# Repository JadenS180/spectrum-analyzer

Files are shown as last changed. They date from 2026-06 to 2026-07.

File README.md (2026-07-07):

# ESP32 Audio Spectrum Analyzer

A real-time audio spectrum analyzer built on the ESP32, featuring a custom-designed PCB. Captures audio via an I2S MEMS microphone, runs FFT processing on-chip, displays a live 16-bar frequency spectrum on an OLED display, and streams real-time FFT data over WiFi to a browser-based visualizer via WebSockets.

---

## Demo Videos

**Analyzer reacting to noise:**

https://github.com/JadenS180/spectrum-analyzer/raw/main/media/spectrum-DemoNoise.MOV

**Analyzer in a quiet environment:**

https://github.com/JadenS180/spectrum-analyzer/raw/main/media/spectrum-DemoQuiet.MOV

---

## Web Dashboard

### Reacting to noise
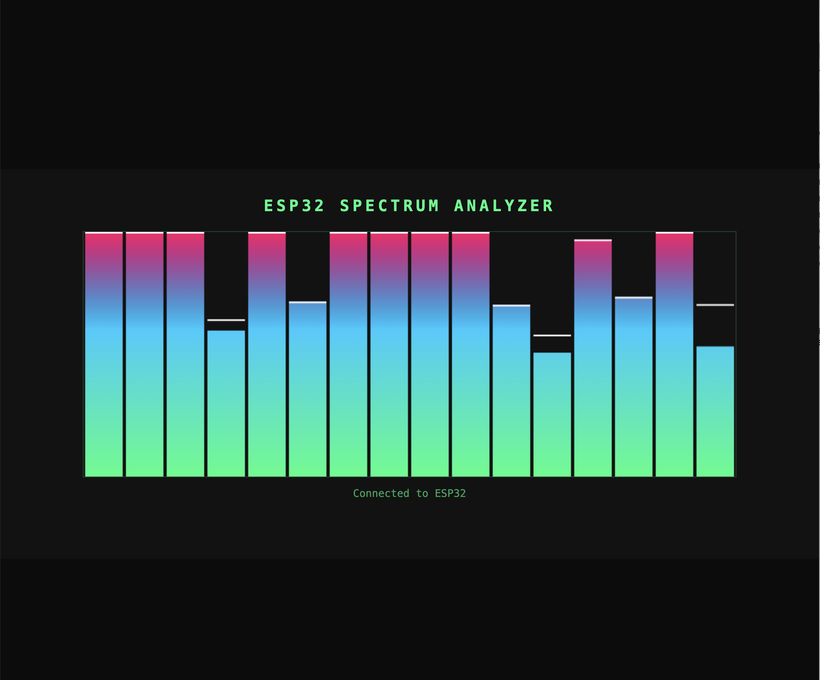
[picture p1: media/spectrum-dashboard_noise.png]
Dashboard Noise


### Quiet environment
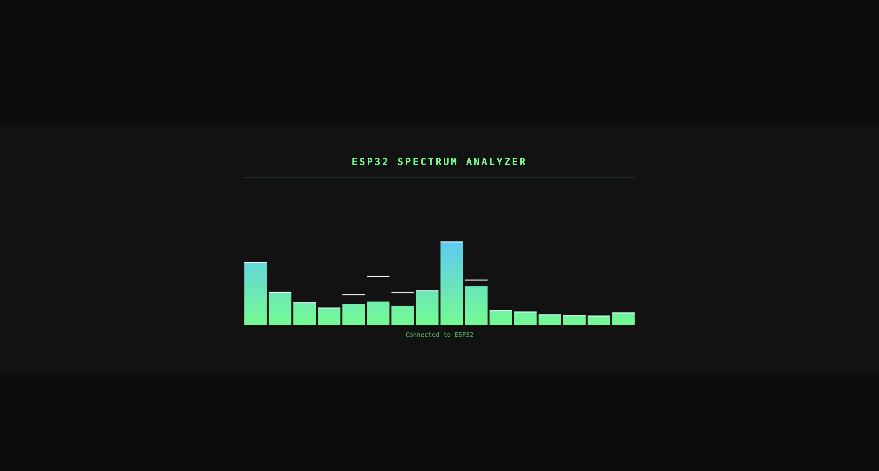
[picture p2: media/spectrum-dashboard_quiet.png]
Dashboard Quiet


---

## Photos

### Full Breadboard Build
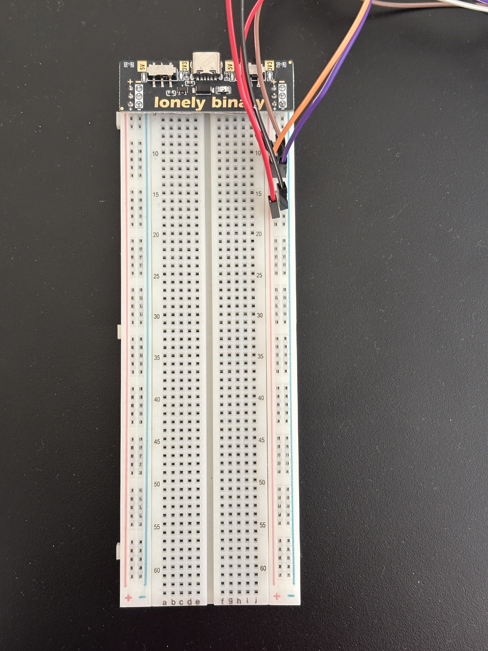
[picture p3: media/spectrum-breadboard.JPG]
Breadboard


### Side Views
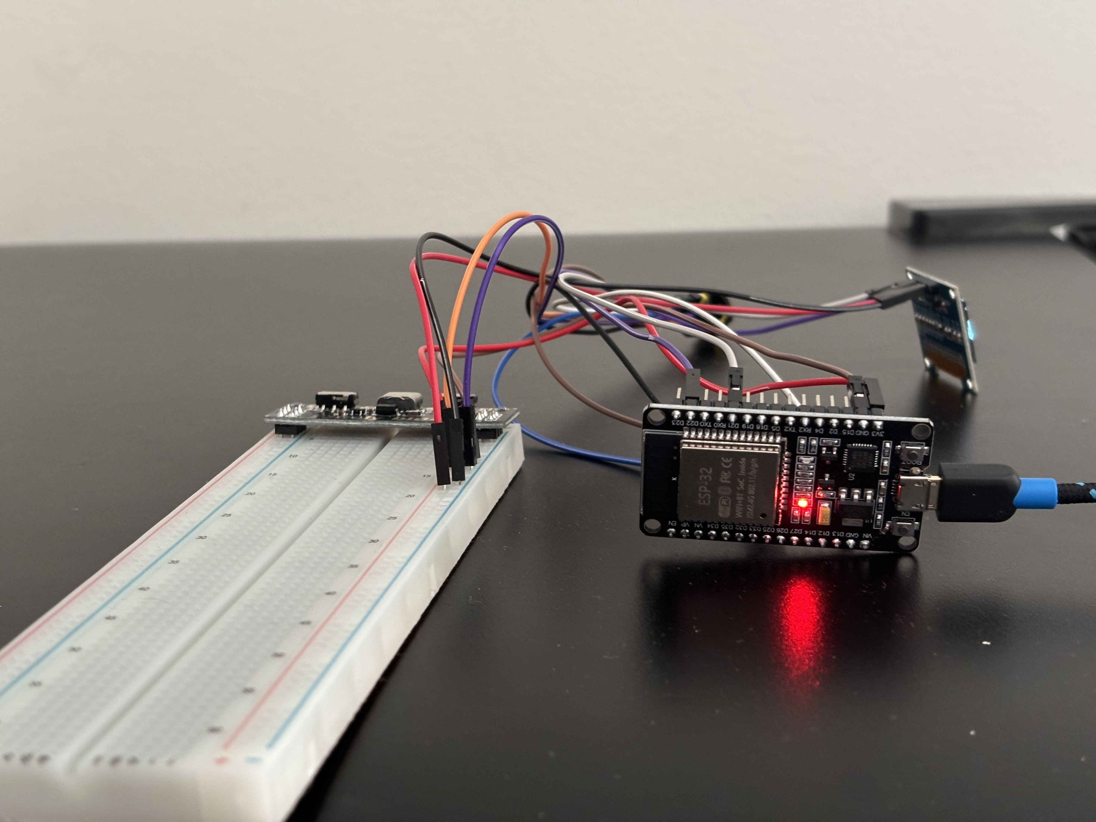
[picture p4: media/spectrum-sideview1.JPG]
Side View 1

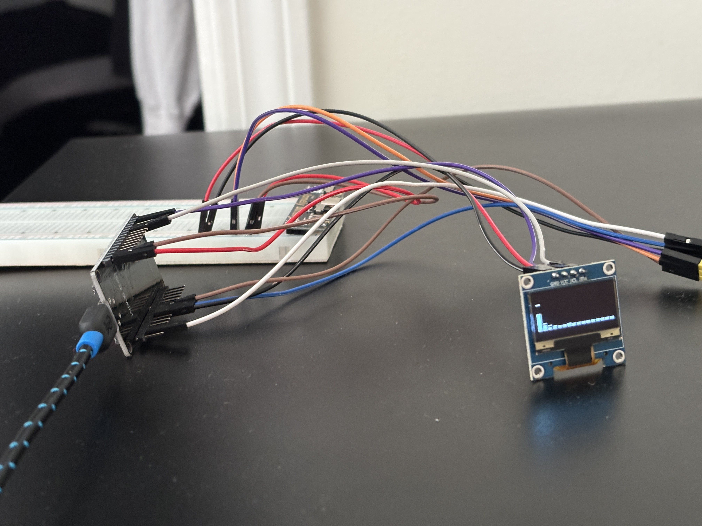
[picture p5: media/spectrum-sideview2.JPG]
Side View 2

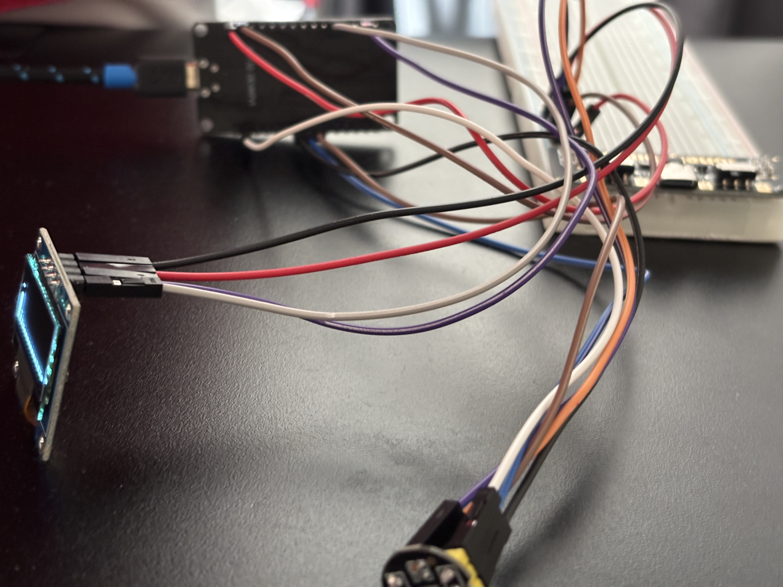
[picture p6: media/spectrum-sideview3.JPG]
Side View 3


### Components
| | |
|---|---|
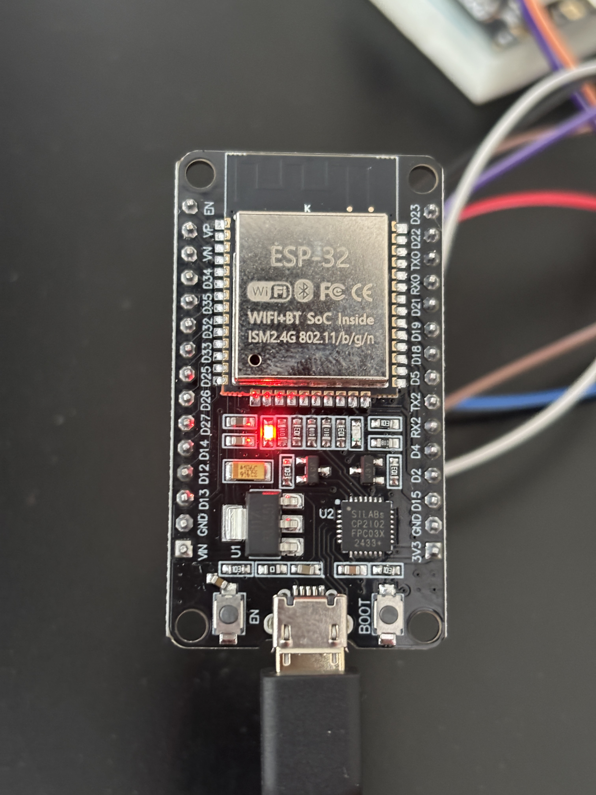
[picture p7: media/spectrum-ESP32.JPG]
ESP32 Front
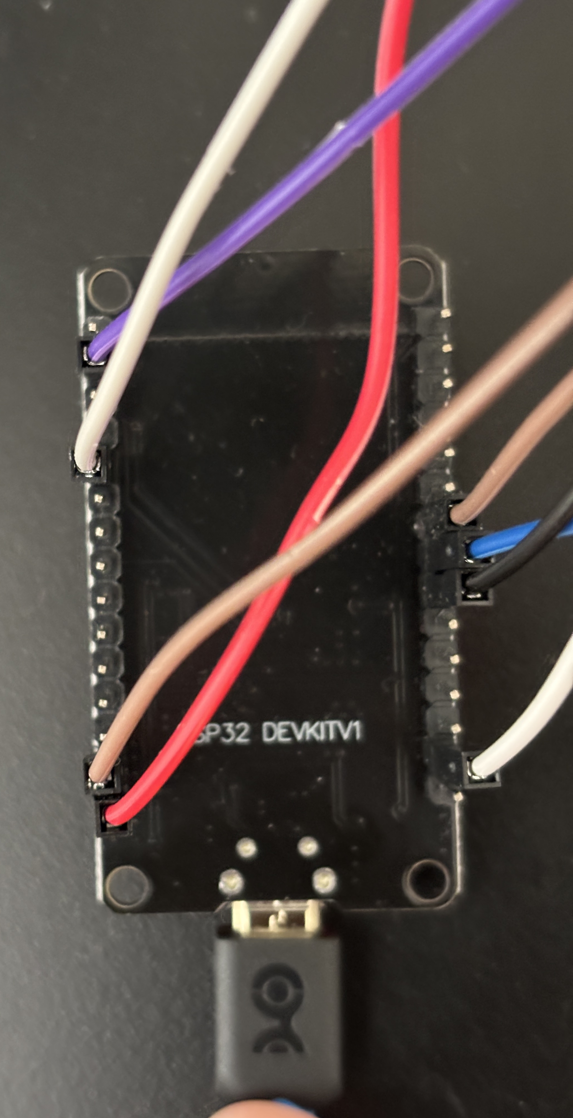
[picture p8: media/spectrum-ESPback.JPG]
ESP32 Back
|  |  |
| ESP32-WROOM-32 (front) | ESP32-WROOM-32 (back) |
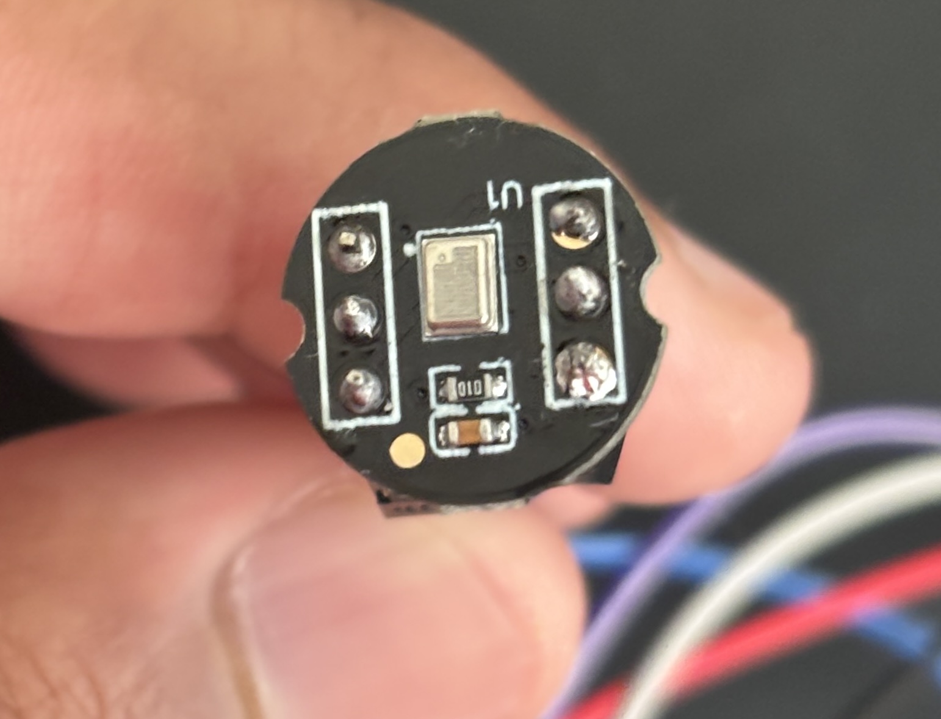
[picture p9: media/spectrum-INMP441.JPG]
INMP441 Front
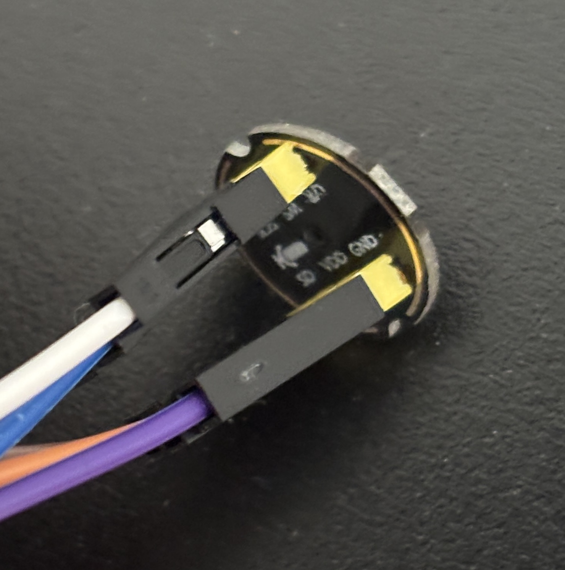
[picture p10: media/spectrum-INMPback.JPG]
INMP441 Back
|  |  |
| INMP441 Microphone (front) | INMP441 Microphone (back) |
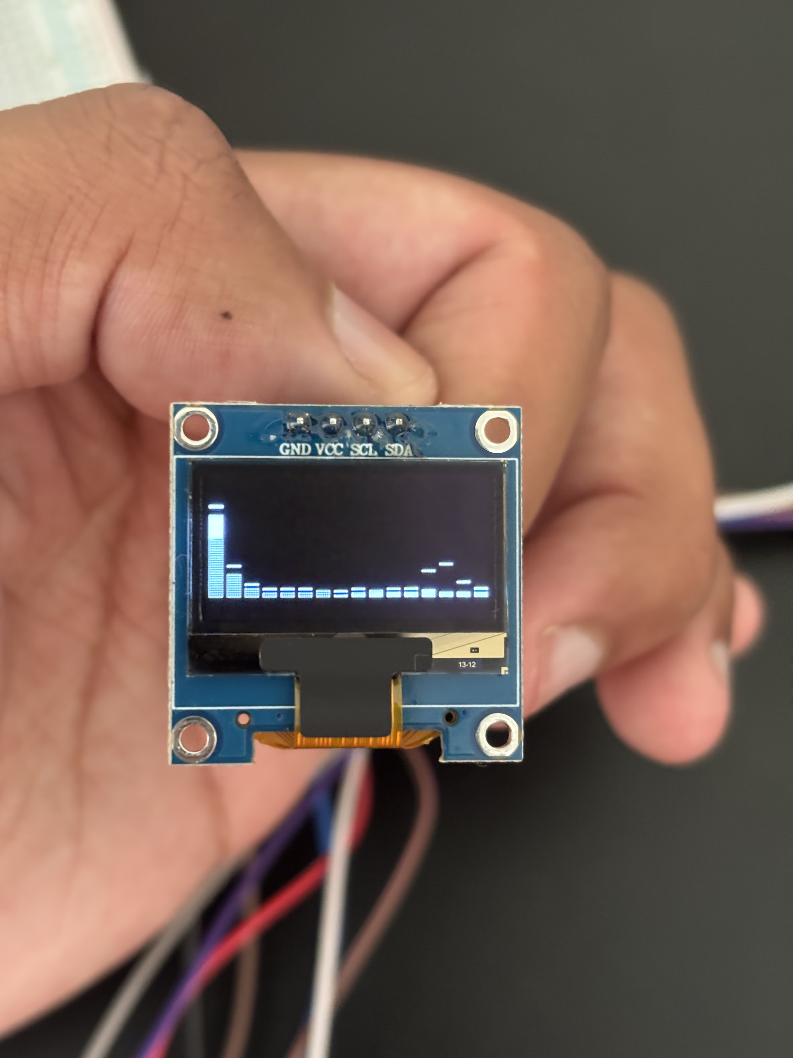
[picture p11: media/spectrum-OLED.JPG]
OLED Front
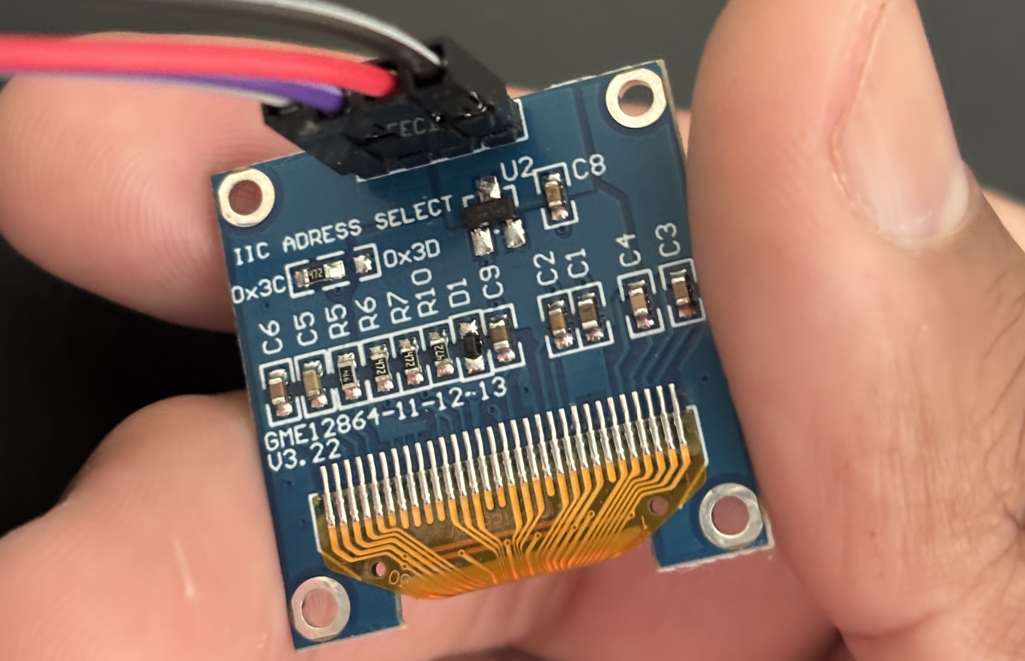
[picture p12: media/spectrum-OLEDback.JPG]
OLED Back
|  |  |
| SSD1306 OLED (front) | SSD1306 OLED (back) |

### PCB
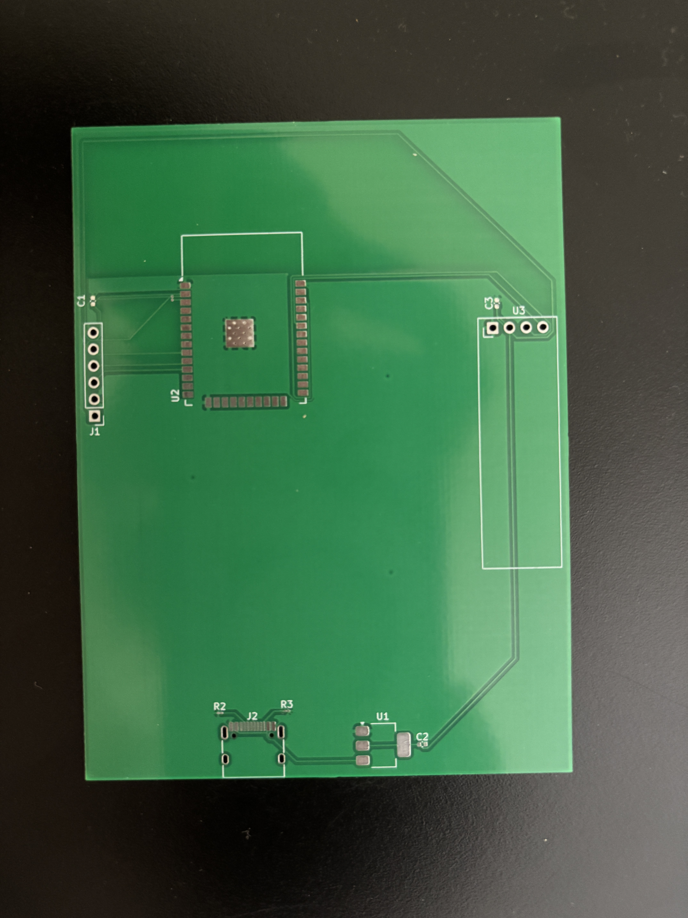
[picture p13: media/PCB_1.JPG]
PCB Front

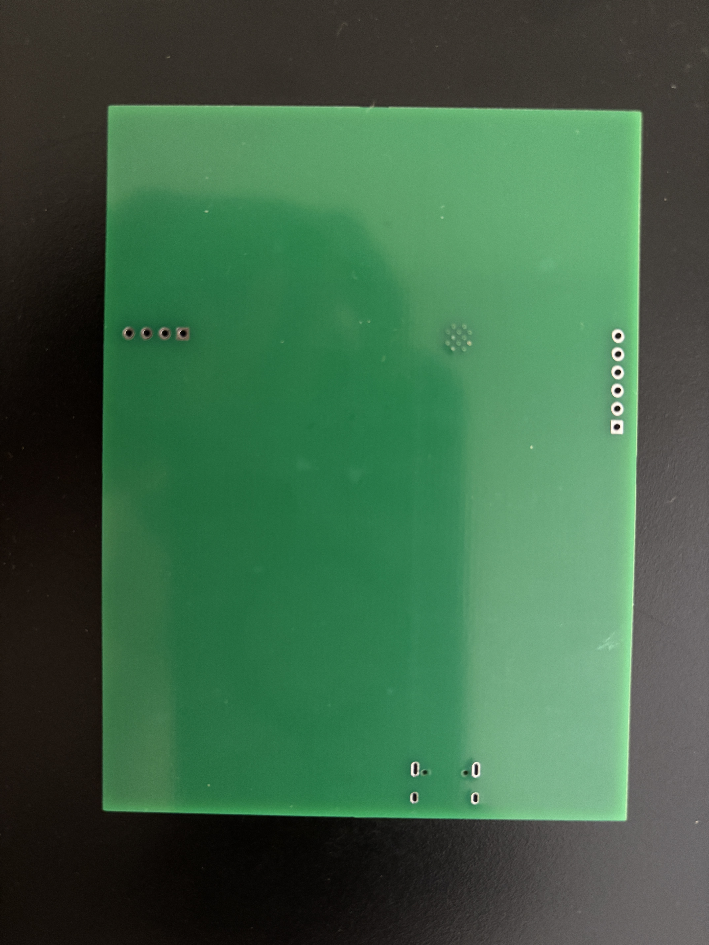
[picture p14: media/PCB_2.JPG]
PCB Back


---

## Features

- Real-time FFT using 512-sample windows at 44,100 Hz
- 16 frequency bars mapped across the audible spectrum
- Hann windowing to reduce spectral leakage
- Peak hold indicators on each bar
- DC/low-frequency noise suppression via bin offset
- Custom 2-layer PCB designed in KiCad and manufactured by JLCPCB
- WiFi streaming via WebSockets to a browser-based canvas visualizer

---

## Hardware

| Component | Description |
|---|---|
| ESP32-WROOM-32 | Microcontroller |
| INMP441 | I2S MEMS microphone |
| SSD1306 | 0.91" I2C OLED display (128x32) |
| AMS1117-3.3 | 3.3V LDO voltage regulator |
| USB-C Receptacle | Power input |

### Pin Mapping

| Signal | ESP32 GPIO |
|---|---|
| I2S SCK | 26 |
| I2S WS | 25 |
| I2S SD | 33 |
| I2C SDA | 21 |
| I2C SCL | 22 |

---

## Firmware

Written in Arduino C++ using the Espressif ESP32 package (v3.3.10).

**Dependencies:**
- [arduinoFFT](https://github.com/kosme/arduinoFFT)
- [Adafruit SSD1306](https://github.com/adafruit/Adafruit_SSD1306)
- [Adafruit GFX Library](https://github.com/adafruit/Adafruit-GFX-Library)
- [WebSockets](https://github.com/Links2004/arduinoWebSockets)
- [ArduinoJson](https://github.com/bblanchon/ArduinoJson)

**To flash:**
1. Open firmware/spectrum_analyzer.ino in Arduino IDE
2. Set your WiFi credentials in the firmware
3. Select board: ESP32 Dev Module under Espressif Systems
4. Connect ESP32 via USB and select the correct port
5. Upload

---

## Web Dashboard

The dashboard is a single HTML file in the `dashboard/` directory. Open it in a browser while the ESP32 is powered and connected to WiFi. Update the WebSocket IP in `index.html` to match your ESP32's IP address.

---

## PCB Design

Designed in KiCad. The board is a 2-layer FR-4 PCB with a filled GND copper pour on F.Cu and a keep-out zone over the ESP32 antenna. Manufactured by JLCPCB.

KiCad schematic, PCB layout, and Gerber files are in the hardware/ directory.

---

## Repository Structure

```
spectrum-analyzer/
├── firmware/
│   └── spectrum_analyzer.ino
├── hardware/
│   ├── spectrum_analyzer.kicad_pro
│   ├── spectrum_analyzer.kicad_sch
│   ├── spectrum_analyzer.kicad_pcb
│   └── gerbers/
├── dashboard/
│   └── index.html
├── media/
│   ├── (photos)
│   └── (videos)
└── README.md
```

---

## Author

Jaden Smiles — [github.com/JadenS180](https://github.com/JadenS180)

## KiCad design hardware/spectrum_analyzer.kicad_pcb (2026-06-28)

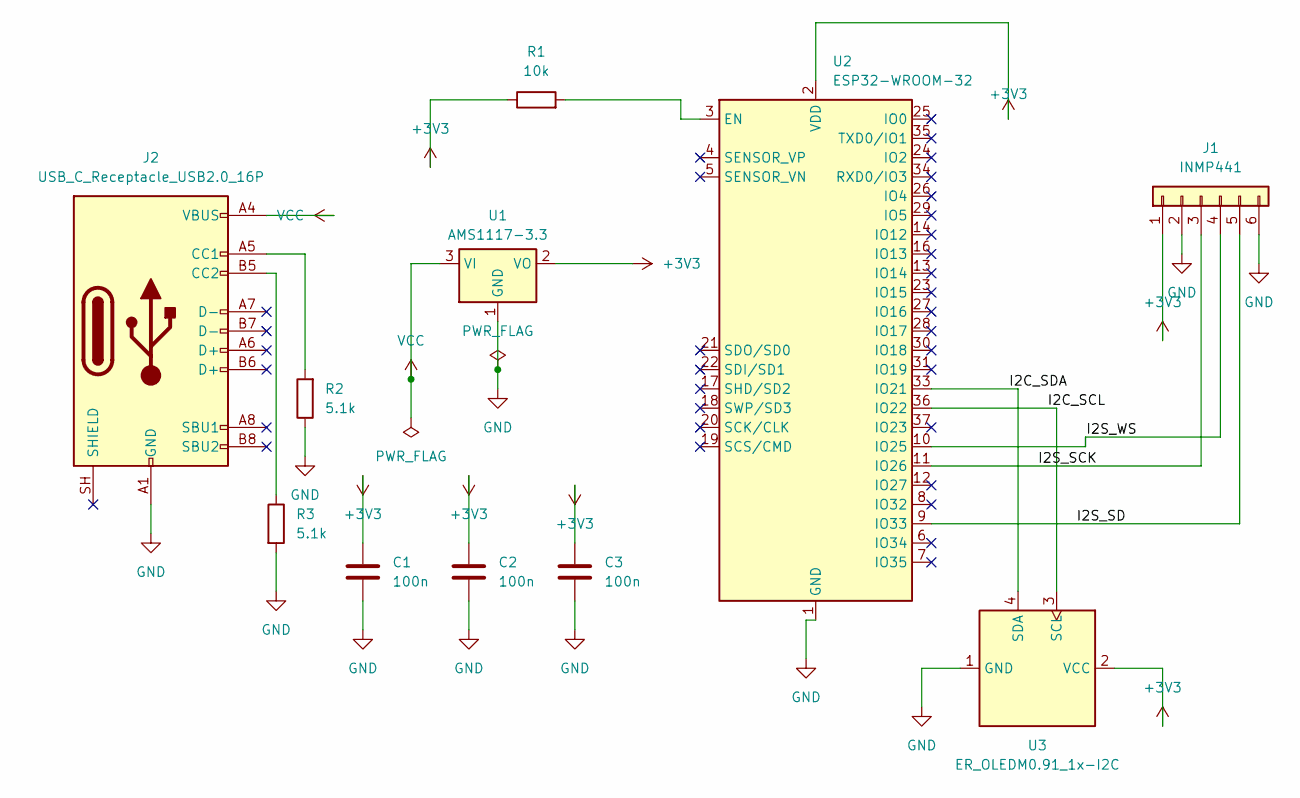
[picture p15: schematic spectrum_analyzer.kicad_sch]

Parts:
C1, C2, C3: 100n; C_0402_1005Metric
J1: INMP441; PinHeader_1x06_P2.54mm_Vertical
J2: USB_C_Receptacle_USB2.0_16P; USB_C_Receptacle_HRO_TYPE-C-31-M-12
R1: 10k; R_01005_0402Metric
R2, R3: 5.1k; R_01005_0402Metric
U1: AMS1117-3.3; SOT-223-3_TabPin2
U2: ESP32-WROOM-32
U3: ER_OLEDM0.91_1x-I2C

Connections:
+3V3: C1.1, C2.1, C3.1, J1.1, R1.1, U1.2 (VO), U2.2 (VDD), U3.2 (VCC)
/I2C_SCL: U2.36 (IO22), U3.3 (SCL)
/I2C_SDA: U2.33 (IO21), U3.4 (SDA)
/I2S_SCK: J1.3, U2.11 (IO26)
/I2S_SD: J1.5, U2.9 (IO33)
/I2S_WS: J1.4, U2.10 (IO25)
GND: C1.2, C2.2, C3.2, J1.2, J1.6, J2.A1 (GND), J2.A12 (GND), J2.B1 (GND), J2.B12 (GND), R2.1, R3.2, U1.1 (GND), U2.1 (GND), U2.15 (GND), U2.38 (GND), U2.39 (GND), U3.1 (GND)
unnamed: J2.A5 (CC1), R2.2
unnamed: J2.B5 (CC2), R3.1
unnamed: R1.2, U2.3 (EN)
VCC: J2.A4 (VBUS), J2.A9 (VBUS), J2.B4 (VBUS), J2.B9 (VBUS), U1.3 (VI)

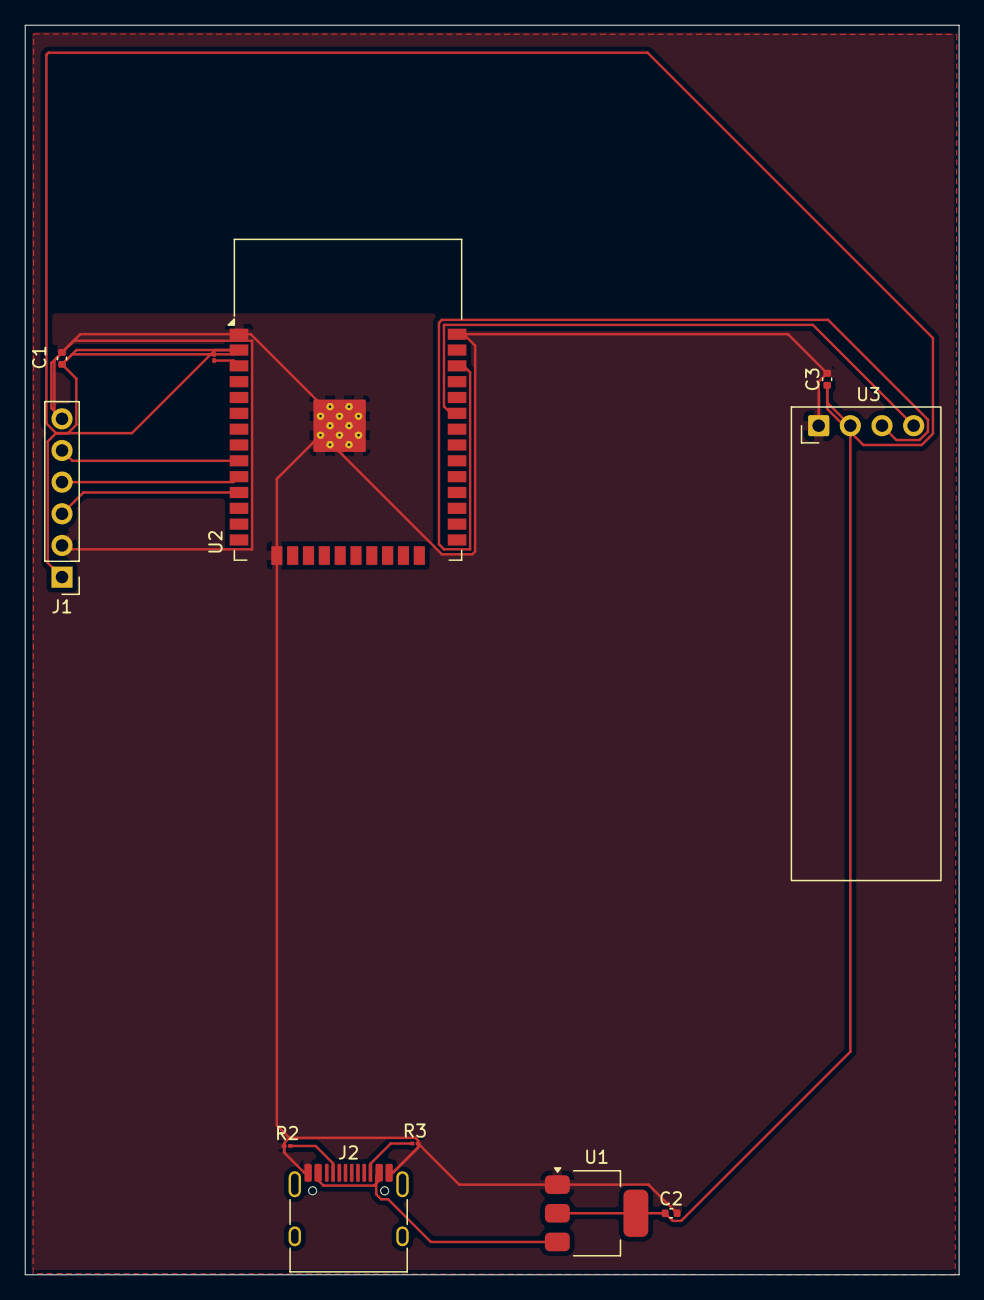
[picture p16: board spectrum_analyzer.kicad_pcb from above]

Board: 2 copper layers, 74.9 x 100.3 mm, 11 parts (0 on the bottom side), 11 nets.

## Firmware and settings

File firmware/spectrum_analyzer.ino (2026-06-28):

/*
  Blink

  Turns an LED on for one second, then off for one second, repeatedly.

  Most Arduinos have an on-board LED you can control. On the UNO, MEGA and ZERO
  it is attached to digital pin 13, on MKR1000 on pin 6. LED_BUILTIN is set to
  the correct LED pin independent of which board is used.
  If you want to know what pin the on-board LED is connected to on your Arduino
  model, check the Technical Specs of your board at:
  https://docs.arduino.cc/hardware/

  modified 8 May 2014
  by Scott Fitzgerald
  modified 2 Sep 2016
  by Arturo Guadalupi
  modified 8 Sep 2016
  by Colby Newman

  This example code is in the public domain.

  https://docs.arduino.cc/built-in-examples/basics/Blink/
*/

#include <driver/i2s.h>
#include <arduinoFFT.h>
#include <Wire.h>
#include <Adafruit_GFX.h>
#include <Adafruit_SSD1306.h>

// Display
#define SCREEN_WIDTH 128
#define SCREEN_HEIGHT 64
#define OLED_RESET -1
Adafruit_SSD1306 display(SCREEN_WIDTH, SCREEN_HEIGHT, &Wire, OLED_RESET);

// I2S pins
#define I2S_WS  25
#define I2S_SCK 26
#define I2S_SD  33

// FFT
#define SAMPLE_RATE     44100
#define FFT_SAMPLES     512
#define NUM_BARS        16
#define DISPLAY_HEIGHT  54  // leave room for labels

double vReal[FFT_SAMPLES];
double vImag[FFT_SAMPLES];

ArduinoFFT<double> FFT = ArduinoFFT<double>(vReal, vImag, FFT_SAMPLES, SAMPLE_RATE);

// Peak hold
int peaks[NUM_BARS] = {0};
int peakHoldTimer[NUM_BARS] = {0};
#define PEAK_HOLD_FRAMES 20
#define PEAK_DECAY 1

void setup() {
  Serial.begin(115200);

  // Init display
  if (!display.begin(SSD1306_SWITCHCAPVCC, 0x3C)) {
    Serial.println("SSD1306 not found");
    while (true);
  }
  display.clearDisplay();
  display.display();

  // Init I2S
  i2s_config_t i2s_config = {
    .mode = (i2s_mode_t)(I2S_MODE_MASTER | I2S_MODE_RX),
    .sample_rate = SAMPLE_RATE,
    .bits_per_sample = I2S_BITS_PER_SAMPLE_32BIT,
    .channel_format = I2S_CHANNEL_FMT_ONLY_LEFT,
    .communication_format = I2S_COMM_FORMAT_STAND_I2S,
    .intr_alloc_flags = ESP_INTR_FLAG_LEVEL1,
    .dma_buf_count = 8,
    .dma_buf_len = FFT_SAMPLES,
    .use_apll = false,
    .tx_desc_auto_clear = false,
    .fixed_mclk = 0
  };

  i2s_pin_config_t pin_config = {
    .bck_io_num = I2S_SCK,
    .ws_io_num = I2S_WS,
    .data_out_num = I2S_PIN_NO_CHANGE,
    .data_in_num = I2S_SD
  };

  i2s_driver_install(I2S_NUM_0, &i2s_config, 0, NULL);
  i2s_set_pin(I2S_NUM_0, &pin_config);
}

void loop() {
  // Read samples from I2S
  int32_t rawSamples[FFT_SAMPLES];
  size_t bytes_read;
  i2s_read(I2S_NUM_0, rawSamples, sizeof(rawSamples), &bytes_read, portMAX_DELAY);

  // Convert to doubles and apply Hann window
  for (int i = 0; i < FFT_SAMPLES; i++) {
    vReal[i] = (double)(rawSamples[i] >> 8);
    vImag[i] = 0.0;
  }

  // Run FFT
  FFT.windowing(FFTWindow::Hann, FFTDirection::Forward);
  FFT.compute(FFTDirection::Forward);
  FFT.complexToMagnitude();

  // Map FFT bins to display bars
  int barWidth = SCREEN_WIDTH / NUM_BARS;
  int binSize = (FFT_SAMPLES / 2) / NUM_BARS;

  display.clearDisplay();

  for (int bar = 0; bar < NUM_BARS; bar++) {
    // Average magnitude across bins for this bar
    double sum = 0;
    int binOffset = 4;  
    for (int bin = 0; bin < binSize; bin++) {
      sum += vReal[bar * binSize + bin + binOffset];
    }
    double avg = sum / binSize;

    // Scale to display height
    int barHeight = (int)(avg / 300000.0 * DISPLAY_HEIGHT);
    barHeight = constrain(barHeight, 0, DISPLAY_HEIGHT);

    int x = bar * barWidth;
    int y = DISPLAY_HEIGHT - barHeight;

    // Draw bar
    display.fillRect(x + 1, y, barWidth - 2, barHeight, SSD1306_WHITE);

    // Peak hold
    if (barHeight >= peaks[bar]) {
      peaks[bar] = barHeight;
      peakHoldTimer[bar] = PEAK_HOLD_FRAMES;
    } else {
      if (peakHoldTimer[bar] > 0) {
        peakHoldTimer[bar]--;
      } else {
        peaks[bar] = max(0, peaks[bar] - PEAK_DECAY);
      }
    }

    // Draw peak dot
    int peakY = DISPLAY_HEIGHT - peaks[bar];
    if (peaks[bar] > 0) {
      display.drawFastHLine(x + 1, peakY, barWidth - 2, SSD1306_WHITE);
    }
  }

  display.display();
}

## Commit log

2026-06-28 Initial commit: firmware and PCB design files
    [spectrum_analyzer-B_Cu.gbr, spectrum_analyzer-B_Mask.gbr, spectrum_analyzer-B_Paste.gbr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]
2026-06-28 Revise README for ESP32 Audio Spectrum Analyzer
    Updated README to provide detailed project description, features, hardware specifications, firmware instructions, PCB design information, and repository structure.
2026-06-29 Added breadboard prototype photos and demo videos
2026-07-06 Added Bare PCB photos
2026-07-06 ADD PCB photos to README
